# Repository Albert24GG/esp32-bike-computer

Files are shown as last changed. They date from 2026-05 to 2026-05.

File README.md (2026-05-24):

# Wireless Bike Computer

Block diagram

This project is a small wireless bike computer built around two ESP32 modules. It measures wheel movement on the fork, sends the data wirelessly to a handlebar unit, computes ride metrics, and shows them on a touchscreen display.

The project also includes a simple Android app. The phone sends its current coordinates to the bike computer over BLE, and the main module can render offline map tiles from the SD card.

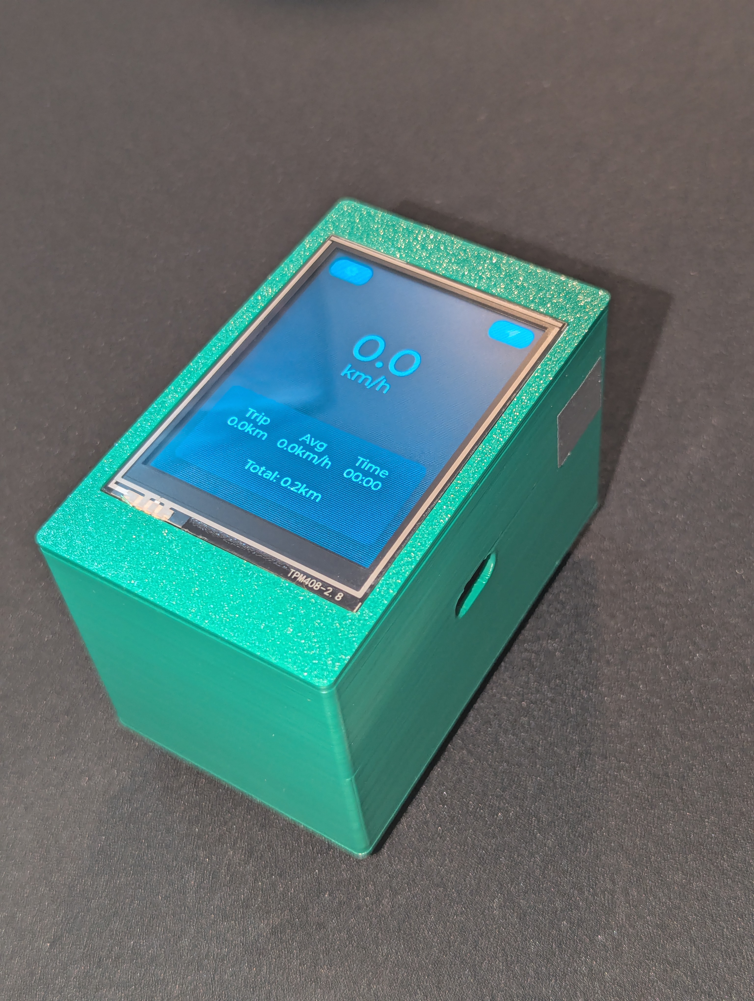
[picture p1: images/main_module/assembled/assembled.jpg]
Main module assembled


## What It Does

The system is split into three parts:

- The wheel module is mounted near the wheel. It uses a Hall effect sensor and a magnet to measure wheel revolutions.
- The main module is mounted on the handlebars. It receives wheel packets, computes the metrics, handles the UI, stores persistent data, and renders maps.
- The Android app runs on the phone. It scans for the bike computer over BLE and sends location coordinates to it.

The two ESP32 modules communicate using ESP-NOW. The main module communicates with the phone using Bluetooth Low Energy.

Main features:

- Current speed
- Trip distance
- Average speed
- Moving time
- Total distance
- Touchscreen UI with metrics, maps, and settings screens
- Persistent settings and ride metrics using NVS
- Configurable wheel circumference, units, brightness, and sleep timeout
- BLE location transfer from Android
- Offline slippy-map tile rendering from SD card
- 3D printed cases for both modules

## How It Works

The wheel module is based on a Seeed Studio XIAO ESP32-C6. It uses the low-power core to detect wheel events and measure the time between revolutions. The high-performance core stays in deep sleep most of the time and only wakes up when data needs to be sent.

The wheel module sends packets that contain:

- a sequence number
- cumulative wheel rotations
- cumulative moving time
- recent wheel periods

The main module is based on a Seeed Studio XIAO ESP32-S3. It receives these packets using ESP-NOW, validates them, computes the ride metrics, and updates the LVGL interface. Metrics are stored internally in metric units and converted only when they are shown on screen.

For the maps screen, the main module starts BLE advertising when the user presses the pairing button. The Android app connects to it and writes the current phone coordinates to a BLE characteristic. The firmware then projects the coordinates to slippy-map tile coordinates and renders the needed RGB565 tiles from the SD card. The current location marker stays fixed in the center of the map viewport.

## Photos

| Main module | Wheel module |
| --- | --- |
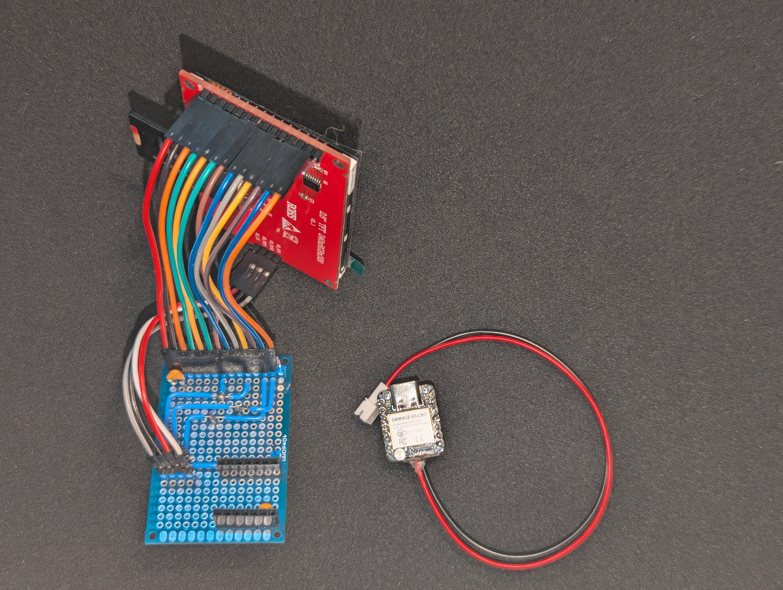
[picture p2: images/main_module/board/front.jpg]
Main module board
|  | Wheel module board |
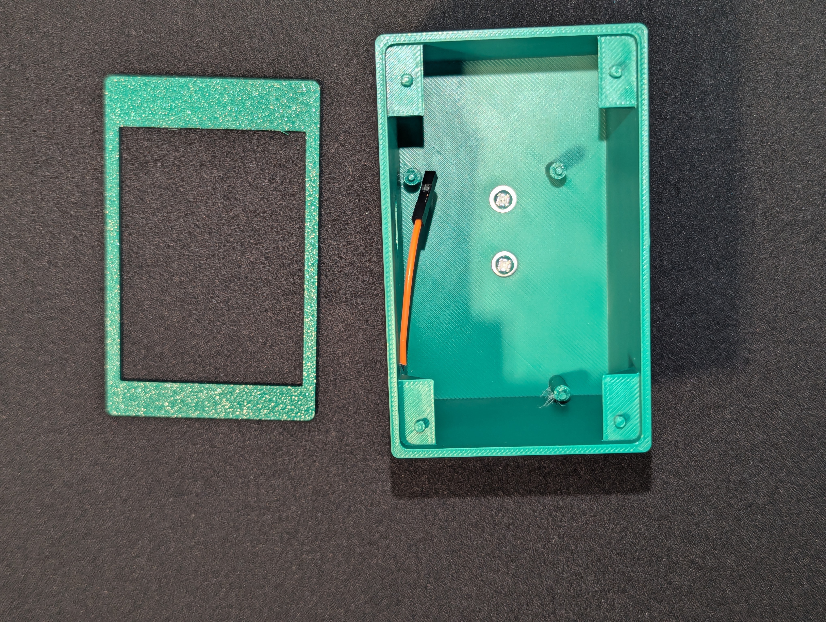
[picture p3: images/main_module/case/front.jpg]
Main module case
|  | Wheel module case |

UI screens:

| Metrics | Maps | Settings |
| --- | --- | --- |
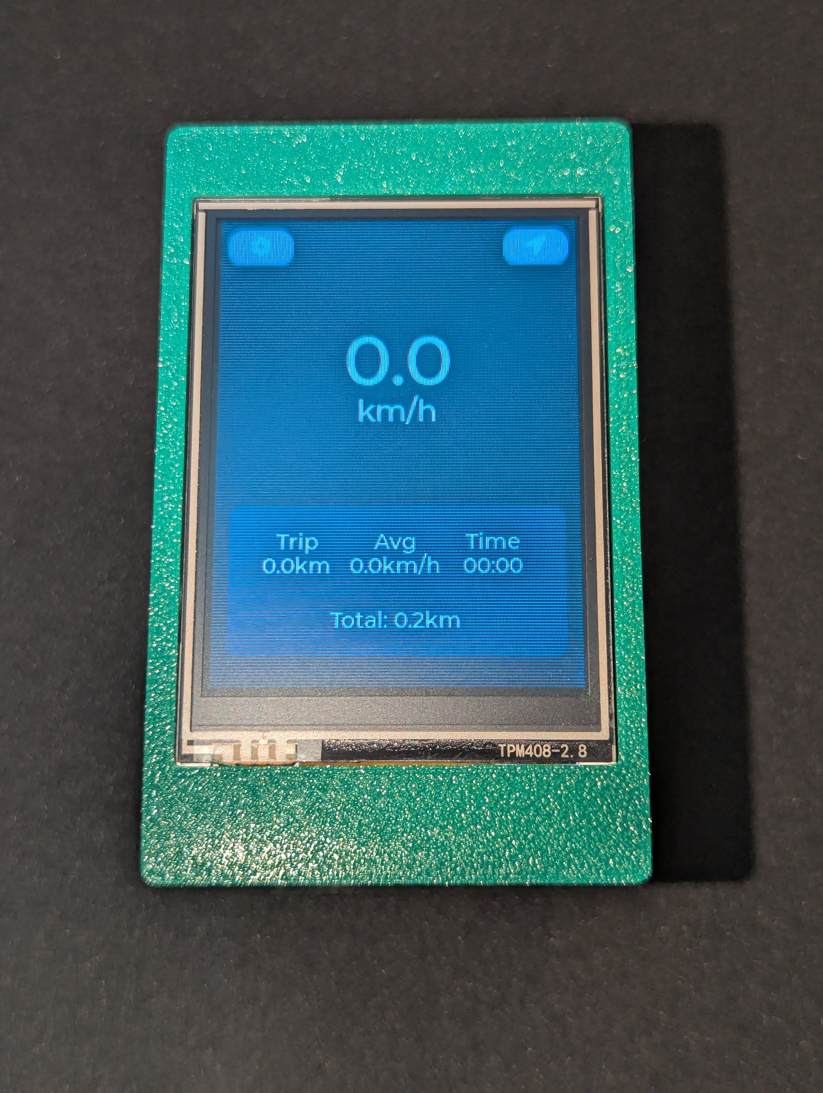
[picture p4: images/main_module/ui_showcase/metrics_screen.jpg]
Metrics screen
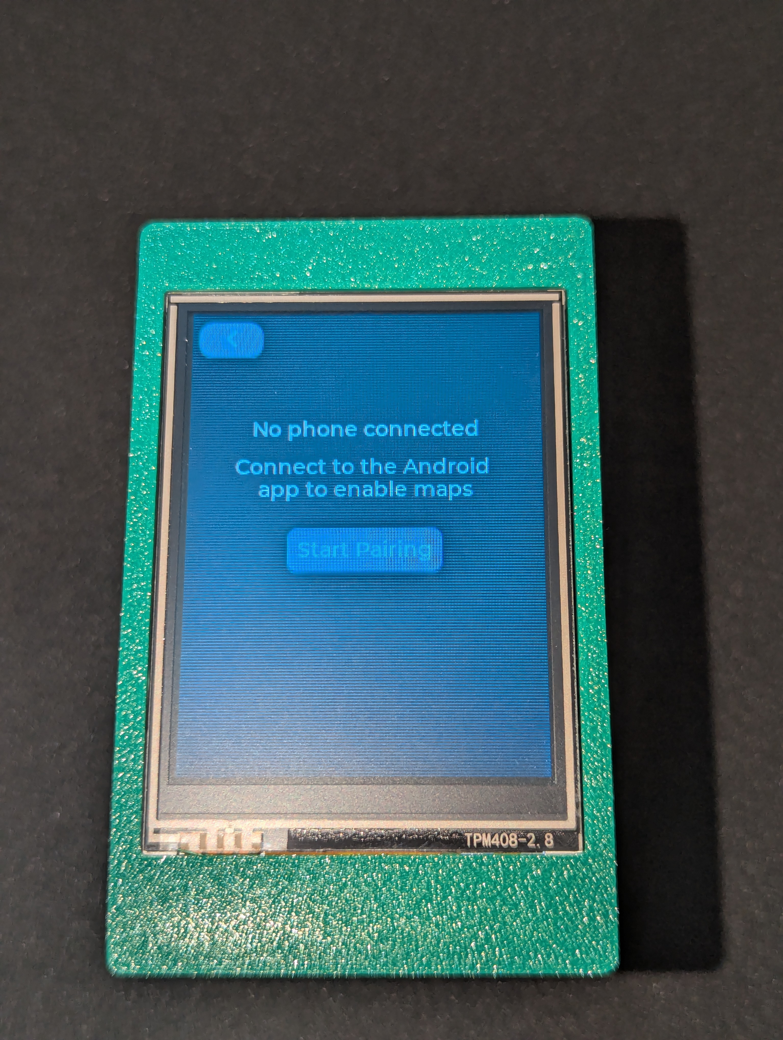
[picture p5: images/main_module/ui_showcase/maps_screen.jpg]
Maps screen
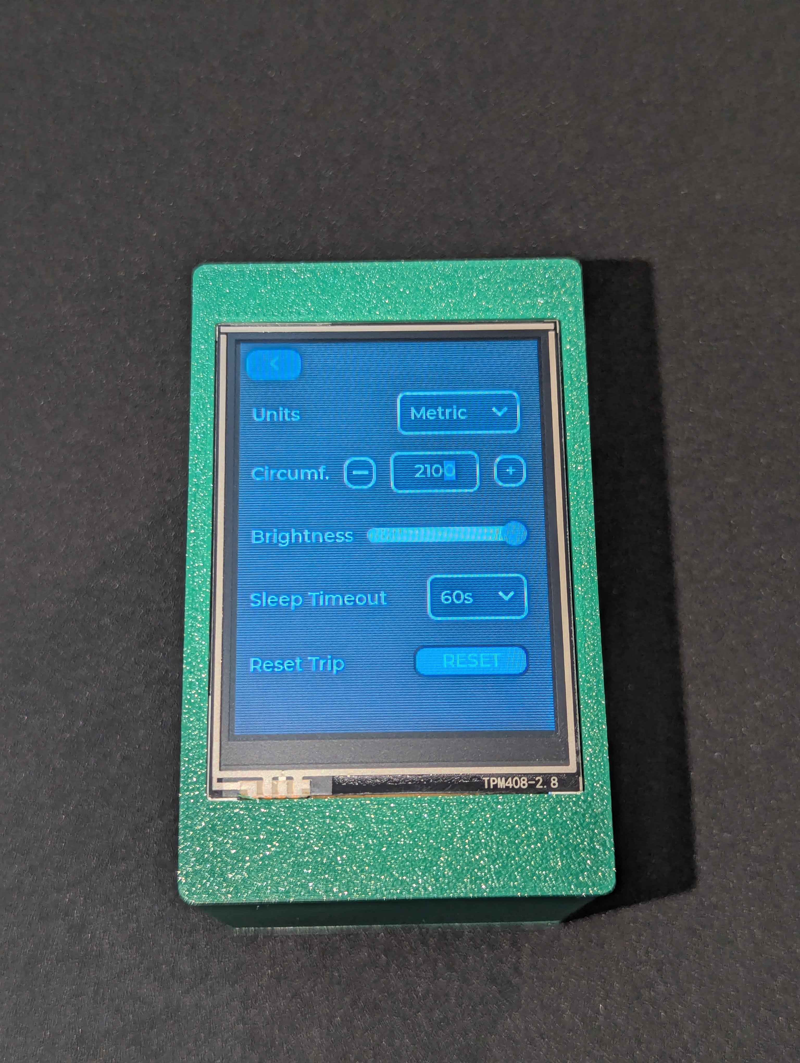
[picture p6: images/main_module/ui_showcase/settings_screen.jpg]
Settings screen
|  |  |  |

## Hardware

### Wheel Module

Main parts:

- Seeed Studio XIAO ESP32-C6
- US5881 Hall effect sensor
- Magnet attached to a wheel spoke
- 5 V boost converter for the Hall sensor
- LiPo battery
- Pull-up resistor and decoupling capacitors

Pinout:

| ESP32-C6 pin | Function |
| --- | --- |
| GPIO0 | Hall effect sensor output |

### Main Module

Main parts:

- Seeed Studio XIAO ESP32-S3
- 2.8 inch ILI9341 display
- XPT2046 touch controller
- SD card reader
- LiPo battery

Pinout:

| ESP32-S3 pin | Function |
| --- | --- |
| GPIO1 | Capacitive touch wake pin |
| GPIO2 | Touch CS |
| GPIO3 | LCD backlight PWM |
| GPIO4 | LCD D/C |
| GPIO5 | LCD reset |
| GPIO6 | LCD CS |
| GPIO7 | SPI CLK, shared |
| GPIO8 | SPI MISO, shared |
| GPIO9 | SPI MOSI, shared |
| GPIO43 | SD card CS |
| GPIO44 | Free |

The LCD, touch controller, and SD card reader share the same SPI bus. Each device has its own chip-select line.

The electrical schematic is available in [`hardware/electrical_schematic.pdf`](hardware/electrical_schematic.pdf). The KiCad project is in [`hardware/bike_computer/`](hardware/bike_computer/).

## Mechanical Design

The project includes 3D printed cases for both modules. The models are in [`mechanical/`](mechanical/).

Main files:

- Main module case: [`mechanical/models/main_module/`](mechanical/models/main_module/)
- Wheel module case: [`mechanical/models/wheel_module/`](mechanical/models/wheel_module/)
- Assembled Fusion models: [`mechanical/models/assembled/`](mechanical/models/assembled/)

The main module case includes a Garmin quarter-turn mount model, so it can be mounted on the handlebars in a similar way to common bike computers.

## Software Structure

The source code is inside [`src/`](src/).

```text
src/
  modules/
    common/        shared ESP-NOW packet definition
    wheel_module/  ESP32-C6 wheel sensor firmware
    main_module/   ESP32-S3 display and application firmware
  android-app/     Android companion app
  tools/           helper tools, including map tile conversion
```

The main module firmware is split into:

- `constants/` for pin assignments and configuration values
- `hardware/` for SPI, display, touch, and SD card setup
- `app/` for the application logic, metrics, storage, BLE, UI presenter, and map renderer
- `components/ui/` for the Squareline Studio generated LVGL UI

The Android app is written in Kotlin. It uses a foreground service for BLE scanning, BLE connection state, location updates, and retrying location writes while the phone screen is off.

## Maps

The firmware does not decode PNG or JPG tiles directly on the ESP32. The tiles are converted on the computer to raw RGB565 files and then copied to the SD card.

The expected SD card layout is:

```text
/sdcard/maps/<zoom>/<x>/<y>.rgb565
```

For example, for zoom level 16:

```text
/sdcard/maps/16/37474/23718.rgb565
```

The conversion tool is:

```sh
python3 src/tools/convert_raster_tiles.py <input-tile-root> <format> <output-root>
```

Example:

```sh
python3 src/tools/convert_raster_tiles.py raster_tiles_example/Bucharest/16 png raster_tiles_converted/16 --overwrite
```

The output directory can then be copied to the SD card under `maps/16`.

## Setup

Required tools:

- ESP-IDF 6.0.1 or a compatible ESP-IDF version
- Python 3
- Android Studio for the Android app
- Pillow and optionally NumPy for the tile conversion tool
- Squareline Studio only if the UI project needs to be edited

Install Python dependencies for the tile converter:

```sh
python3 -m pip install pillow numpy
```

The ESP-IDF projects use `sdkconfig.defaults`, so the target and important options should already be set. The main module enables PSRAM because the map canvas buffer is too large for internal SRAM.

## Build and Flash

### Wheel Module

```sh
cd src/modules/wheel_module
idf.py build
idf.py flash monitor
```

This builds and flashes the ESP32-C6 wheel module firmware.

### Main Module

```sh
cd src/modules/main_module
idf.py build
idf.py flash monitor
```

This builds and flashes the ESP32-S3 main module firmware.

### Android App

```sh
cd src/android-app
./gradlew assembleDebug
```

The generated debug APK can be installed from Android Studio or with `adb install`.

The app needs Bluetooth, location, and notification permissions. Location must also be enabled on the phone.

## Running the System

1. Flash the wheel module and main module.
2. (Optional) Copy converted map tiles to the SD card under `maps/<zoom>/`, then insert the SD card into the display module .
4. Power the wheel module and place the magnet near the Hall sensor path.
5. Power the main module.
6. (Optional) Open the Android app.
7. (Optional) Go to the maps screen on the bike computer and press the pairing button.
8. (Optional) Start scanning in the Android app.

After the phone connects, the app sends coordinates to the ESP32-S3 and the maps screen updates with the current location.

## Current Limitations

- The map zoom level is fixed in firmware.
- The project is still a prototype, with hand-wired hardware.
- Battery percentage measurement is not implemented yet.
- Map data must be prepared manually and copied to the SD card.
- BLE and ESP-NOW share the same 2.4 GHz radio, so connection behavior can depend on signal conditions and phone behavior.

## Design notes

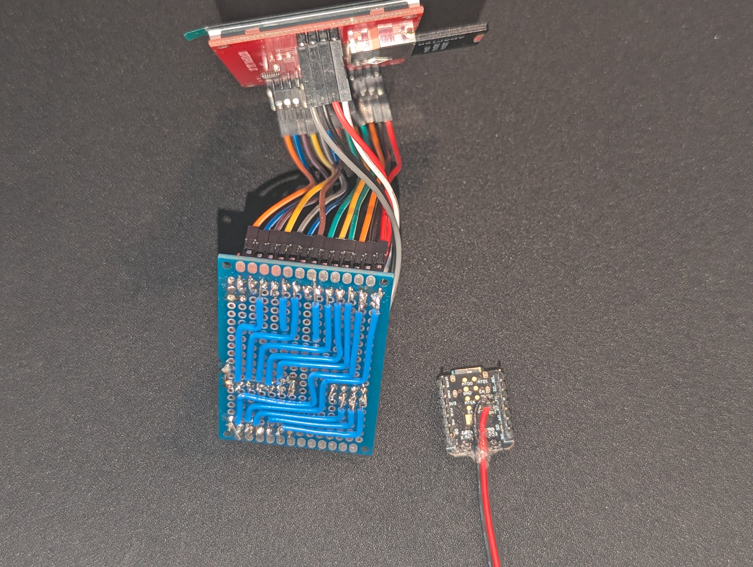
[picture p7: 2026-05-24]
images/main_module/board/back.jpg

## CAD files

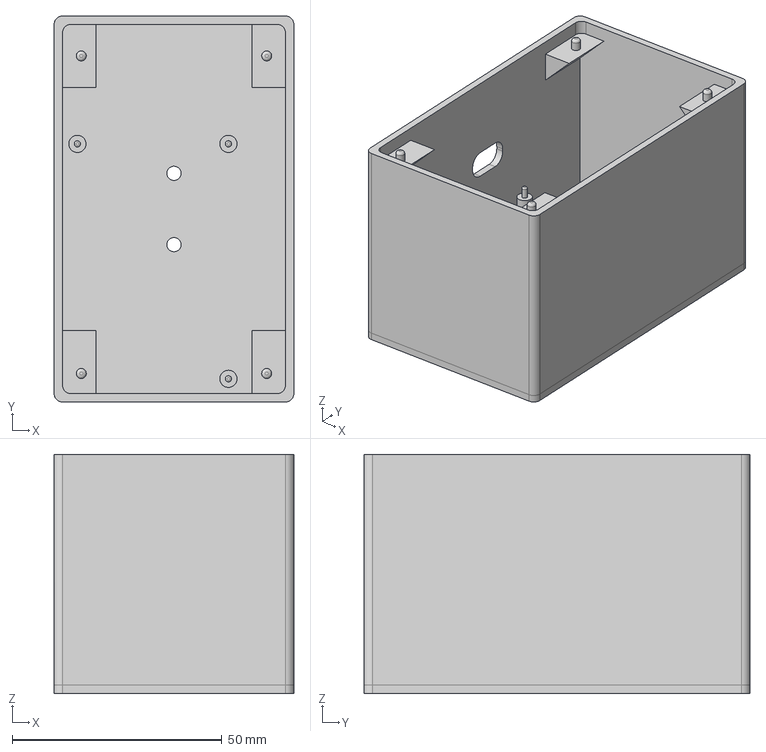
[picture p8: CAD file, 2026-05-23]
mechanical/models/main_module/bottom_case/BottomCase.step
57.1 x 92.0 x 57.0 mm

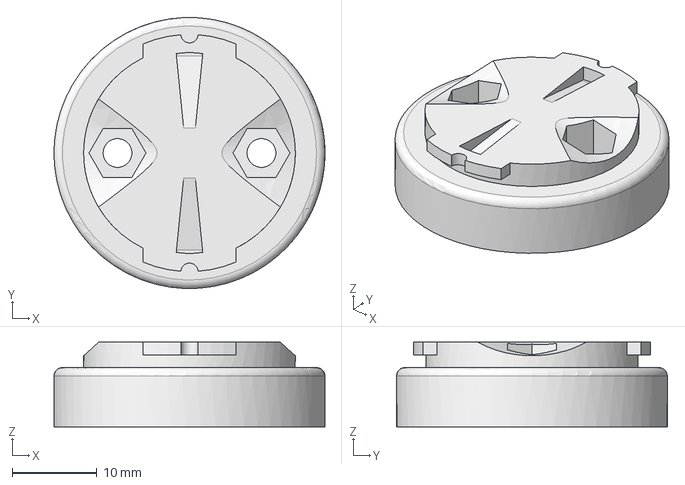
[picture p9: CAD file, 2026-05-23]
mechanical/models/main_module/garmin_mount/Quarter-turn_v6.step
32.0 x 32.0 x 10.0 mm

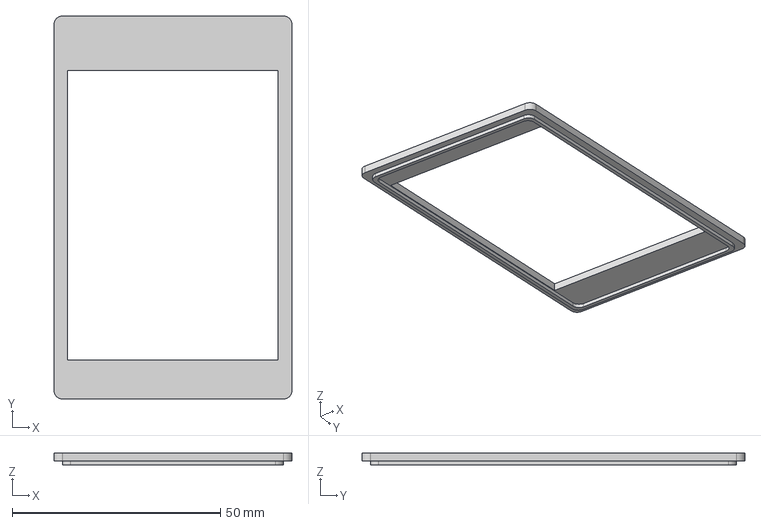
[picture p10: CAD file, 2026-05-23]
mechanical/models/main_module/top_lid/TopLid.step
57.1 x 92.0 x 3.00 mm

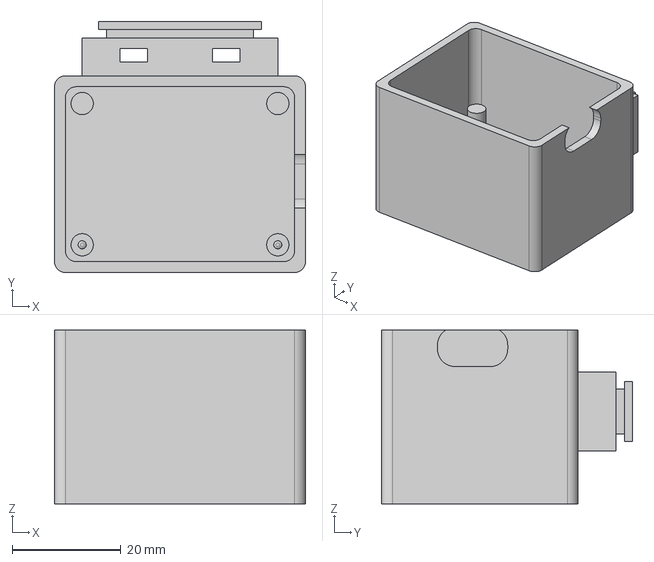
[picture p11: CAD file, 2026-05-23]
mechanical/models/wheel_module/bottom_case/BottomCase.step
46.2 x 46.2 x 32.0 mm

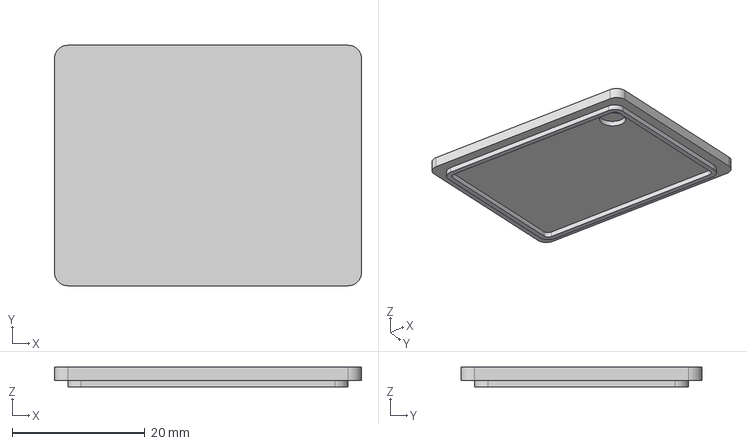
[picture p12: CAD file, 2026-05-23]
mechanical/models/wheel_module/top_lid/TopLid.step
46.2 x 36.2 x 3.00 mm

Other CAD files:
mechanical/models/main_module/bottom_case/BottomCase.3mf
mechanical/models/main_module/garmin_mount/Quarter-turn_v6.3mf
mechanical/models/main_module/top_lid/TopLid.3mf
mechanical/models/wheel_module/bottom_case/BottomCase.3mf
mechanical/models/wheel_module/top_lid/TopLid.3mf

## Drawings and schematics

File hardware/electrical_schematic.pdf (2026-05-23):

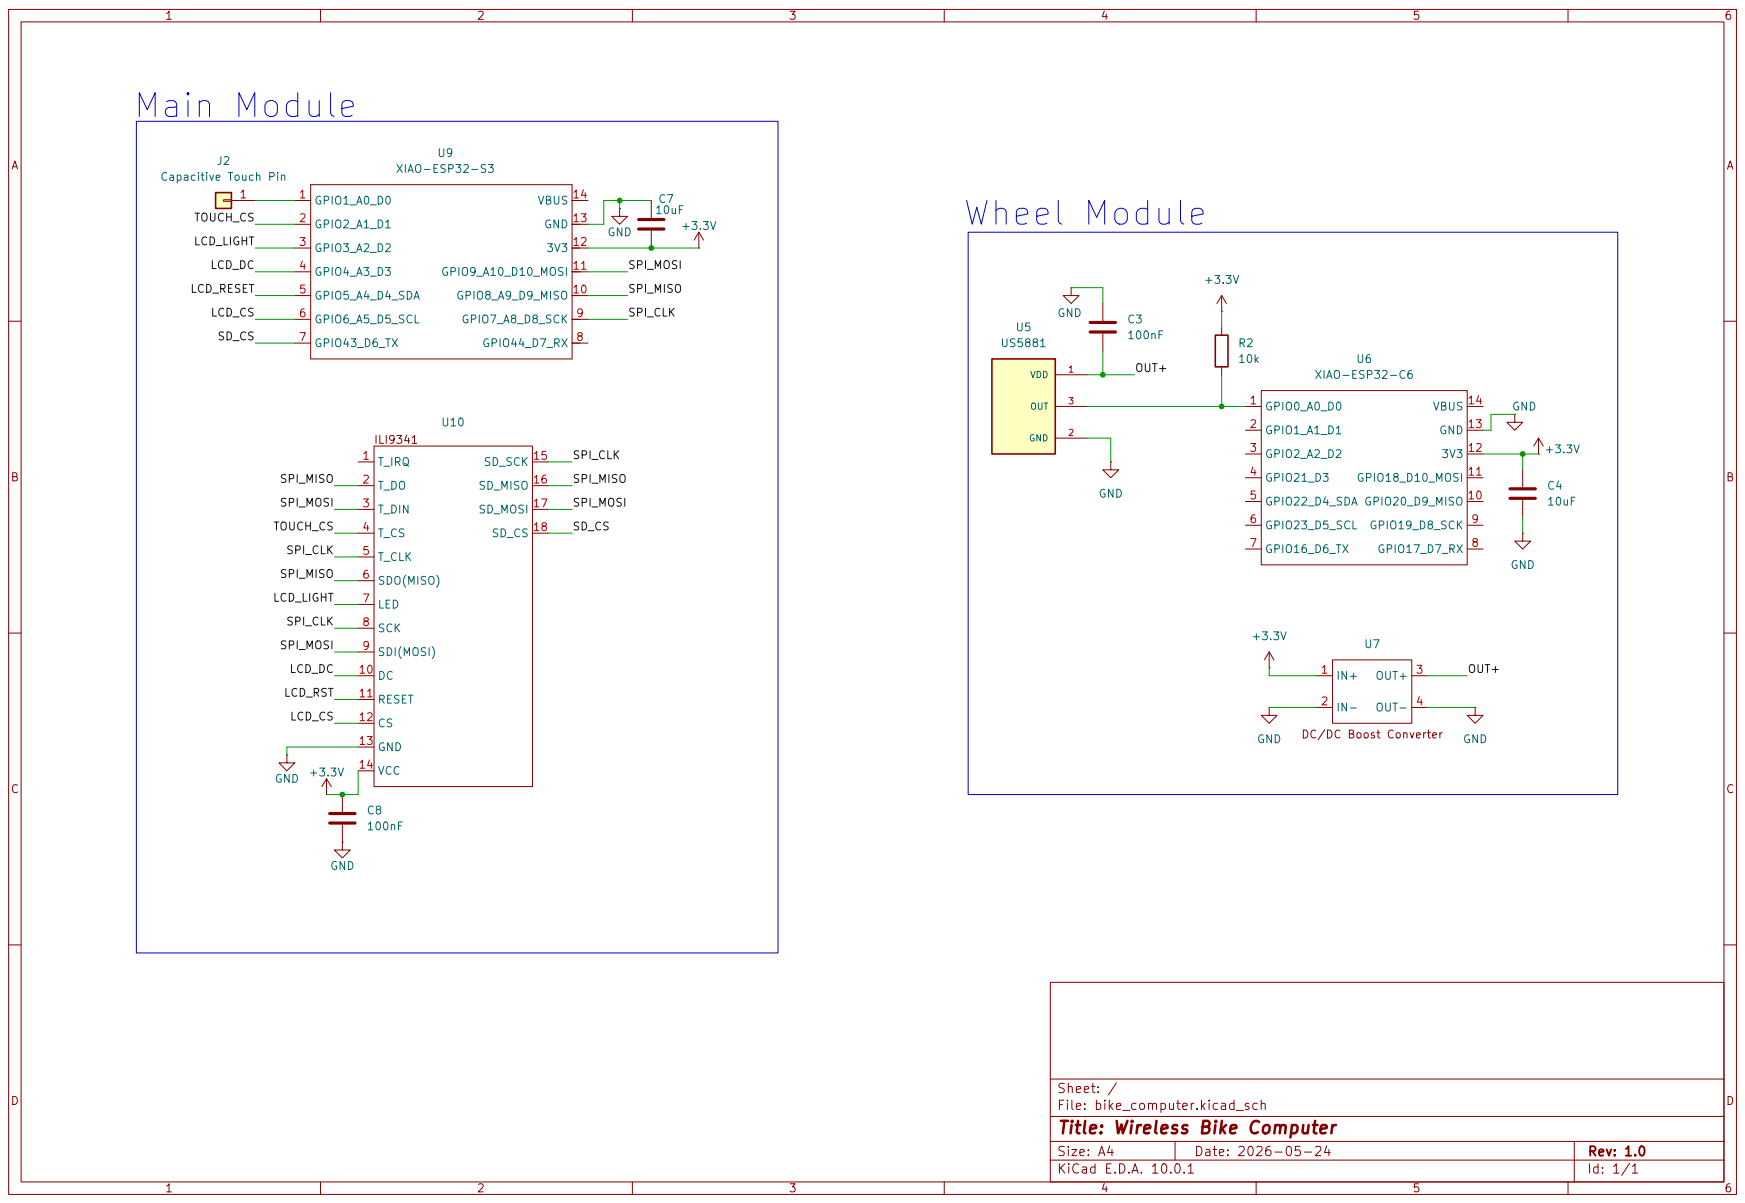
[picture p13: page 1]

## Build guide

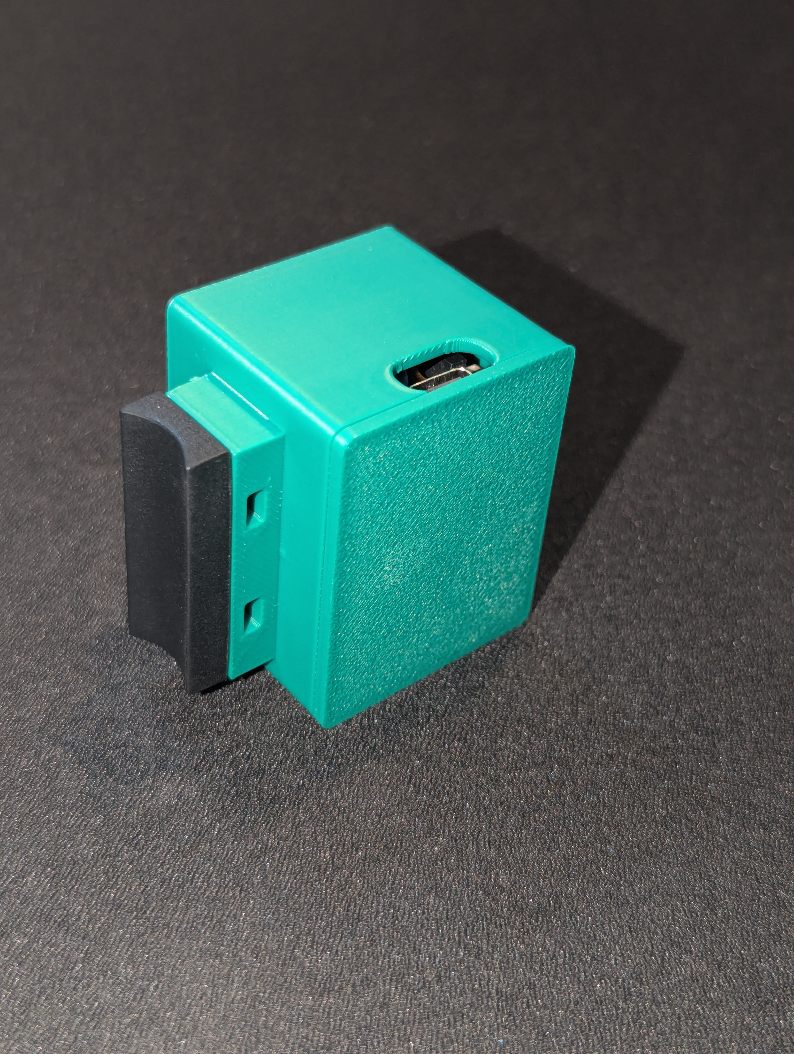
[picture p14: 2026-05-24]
images/wheel_module/assembled/assembled.jpg

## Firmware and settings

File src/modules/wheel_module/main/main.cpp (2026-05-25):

#include "driver/rtc_io.h"
#include "driver/uart.h"
#include "esp_attr.h"
#include "esp_err.h"
#include "esp_log.h"
#include "esp_now.h"
#include "esp_private/esp_clk.h"
#include "esp_sleep.h"
#include "esp_wifi.h"
#include "nvs.h"
#include "nvs_flash.h"
#include "soc/rtc.h"
#include "ulp_lp_core.h"

#include "../../common/espnow_packet.hpp"
#include "ulp_main.h"

#include "constants.hpp"
#include <cstdint>

extern const uint8_t ulp_main_bin_start[] asm("_binary_ulp_main_bin_start");
extern const uint8_t ulp_main_bin_end[] asm("_binary_ulp_main_bin_end");

static RTC_DATA_ATTR size_t wakeup_cnt_since_recalibration = 0;
static RTC_DATA_ATTR uint64_t packet_seq = 1;
static RTC_DATA_ATTR uint32_t wheel_boot_id = 0;
static RTC_DATA_ATTR uint32_t slowclk_cal_value = esp_clk_slowclk_cal_get();
static RTC_DATA_ATTR uint64_t cumulative_rotations = 0;
static RTC_DATA_ATTR uint64_t cumulative_ride_time_us = 0;

static uint64_t *shared_periods_buf =
    reinterpret_cast<uint64_t *>(ulp_shared_periods_buf);
static uint32_t &shared_periods_buf_len = ulp_shared_periods_buf_len;
static uint32_t &is_first_wakeup = ulp_is_first_wakeup;
static uint32_t &entered_inactive_state = ulp_entered_inactive_state;

static void init_wifi();
static void init_espnow();
static void init_nvs();
static void init_wheel_boot_id();
static void send_packet(const uint64_t *periods_us, size_t periods_len);
static void recalibrate_slow_clock();

static void wakeup_gpio_init() {
  /* Configure the Hall effect sensor GPIO as input, enable wakeup */
  rtc_gpio_init(SENSOR_PIN);
  rtc_gpio_set_direction(SENSOR_PIN, RTC_GPIO_MODE_INPUT_ONLY);
  rtc_gpio_pulldown_dis(SENSOR_PIN);
  rtc_gpio_pullup_en(SENSOR_PIN);
  rtc_gpio_wakeup_enable(SENSOR_PIN, GPIO_INTR_NEGEDGE);
}

static void
start_ulp_program(uint32_t wakeup_source,
                  uint32_t timer_sleep_duration_us = LP_TIMER_DURATION_US) {
  /* Start the program */
  ulp_lp_core_cfg_t cfg = {
      .wakeup_source = wakeup_source,
      .lp_timer_sleep_duration_us = timer_sleep_duration_us,
  };

  ESP_ERROR_CHECK(ulp_lp_core_run(&cfg));
}

static void
init_ulp_program(uint32_t wakeup_source,
                 uint32_t timer_sleep_duration_us = LP_TIMER_DURATION_US) {
  esp_err_t err = ulp_lp_core_load_binary(
      ulp_main_bin_start, (ulp_main_bin_end - ulp_main_bin_start));
  ESP_ERROR_CHECK(err);
  start_ulp_program(wakeup_source, timer_sleep_duration_us);
}

static void enter_inactive_state() {
  ESP_LOGI(TAG, "Entering inactive state due to inactivity timeout");

  entered_inactive_state = 1;
  is_first_wakeup = 1;
  start_ulp_program(ULP_LP_CORE_WAKEUP_SOURCE_LP_IO);
}

static void exit_inactive_state() {
  ESP_LOGI(TAG, "Exiting inactive state");

  entered_inactive_state = 0;
  start_ulp_program(ULP_LP_CORE_WAKEUP_SOURCE_LP_IO |
                    ULP_LP_CORE_WAKEUP_SOURCE_LP_TIMER);
}

static void handle_ulp_wakeup() {
  ++wakeup_cnt_since_recalibration;

  if (entered_inactive_state == 1 ||
      wakeup_cnt_since_recalibration >= WAKEUP_CNT_BEFORE_RECALIBRATION) {
    wakeup_cnt_since_recalibration = 0;
    recalibrate_slow_clock();
  }

  ulp_lp_core_stop();

  const uint32_t buf_len =
      std::min(shared_periods_buf_len, SHARED_PERIODS_BUF_SIZE);

  if (buf_len > 0) {
    uint64_t periods_buf[SHARED_PERIODS_BUF_SIZE] = {};

    memcpy(periods_buf, shared_periods_buf, buf_len * sizeof(periods_buf[0]));
    shared_periods_buf_len = 0;

    if (entered_inactive_state == 1) {
      entered_inactive_state = 0;
    }

    start_ulp_program(ULP_LP_CORE_WAKEUP_SOURCE_LP_IO |
                      ULP_LP_CORE_WAKEUP_SOURCE_LP_TIMER);

    uint32_t valid_periods_cnt = 0;
    for (size_t i = 0; i < buf_len; ++i) {
      const uint64_t period_us =
          rtc_time_slowclk_to_us(periods_buf[i], slowclk_cal_value);
      if (period_us < MIN_VALID_PERIOD_US) {
        continue;
      }

      periods_buf[valid_periods_cnt++] = period_us;
    }

    send_packet(periods_buf, valid_periods_cnt);

  } else {
    if (entered_inactive_state == 1) {
      exit_inactive_state();
    } else {
      enter_inactive_state();
    }
  }
}

extern "C" void app_main(void) {
  ESP_LOGI(TAG, "Starting HP core\n");

  wakeup_gpio_init();

  if (esp_sleep_get_wakeup_causes() & BIT(ESP_SLEEP_WAKEUP_ULP)) {
    ESP_LOGI(TAG, "Woke up from ULP wakeup");

    handle_ulp_wakeup();
  } else {
    ESP_LOGI(TAG, "Not a ULP wakeup, initializing it!");
    init_wheel_boot_id();
    init_ulp_program(ULP_LP_CORE_WAKEUP_SOURCE_LP_IO |
                     ULP_LP_CORE_WAKEUP_SOURCE_LP_TIMER);
  }

  ESP_ERROR_CHECK(esp_sleep_enable_ulp_wakeup());

  ESP_LOGI(TAG, "Entering deep sleep");

  uart_wait_tx_idle_polling((uart_port_t)CONFIG_ESP_CONSOLE_UART_NUM);
  esp_deep_sleep_start();
}

void init_nvs() {
  esp_err_t ret = nvs_flash_init();
  if (ret == ESP_ERR_NVS_NO_FREE_PAGES ||
      ret == ESP_ERR_NVS_NEW_VERSION_FOUND) {
    ESP_ERROR_CHECK(nvs_flash_erase());
    ESP_ERROR_CHECK(nvs_flash_init());
  } else {
    ESP_ERROR_CHECK(ret);
  }
}

void init_wheel_boot_id() {
  init_nvs();

  nvs_handle_t handle{};
  ESP_ERROR_CHECK(nvs_open("wheel", NVS_READWRITE, &handle));

  uint32_t stored_boot_id{};
  const esp_err_t read_err = nvs_get_u32(handle, "boot_id", &stored_boot_id);
  if (read_err != ESP_OK && read_err != ESP_ERR_NVS_NOT_FOUND) {
    nvs_close(handle);
    ESP_ERROR_CHECK(read_err);
  }

  ++stored_boot_id;
  if (stored_boot_id == 0) {
    stored_boot_id = 1;
  }

  ESP_ERROR_CHECK(nvs_set_u32(handle, "boot_id", stored_boot_id));
  ESP_ERROR_CHECK(nvs_commit(handle));
  nvs_close(handle);

  wheel_boot_id = stored_boot_id;
  packet_seq = 1;
  cumulative_rotations = 0;
  cumulative_ride_time_us = 0;

  ESP_LOGI(TAG, "Wheel boot session initialized: boot_id=%lu",
           static_cast<unsigned long>(wheel_boot_id));
}

void init_wifi() {
  init_nvs();

  ESP_ERROR_CHECK(esp_netif_init());
  ESP_ERROR_CHECK(esp_event_loop_create_default());

  wifi_init_config_t wifi_cfg = WIFI_INIT_CONFIG_DEFAULT();

  ESP_ERROR_CHECK(esp_wifi_init(&wifi_cfg));
  ESP_ERROR_CHECK(esp_wifi_set_storage(WIFI_STORAGE_RAM));
  ESP_ERROR_CHECK(esp_wifi_set_mode(WIFI_MODE_STA));
  ESP_ERROR_CHECK(esp_wifi_start());

  ESP_ERROR_CHECK(esp_wifi_set_channel(ESPNOW_CHANNEL, WIFI_SECOND_CHAN_NONE));
}

void init_espnow() {
  ESP_ERROR_CHECK(esp_now_init());
  ESP_ERROR_CHECK(esp_now_add_peer(&PEER_INFO));
}

static void send_packet(const uint64_t *periods_us, size_t periods_len) {
  init_wifi();
  init_espnow();

  BikePacket packet = {};
  packet.boot_id = wheel_boot_id;
  packet.seq_num = packet_seq++;
  packet.periods_buf_len =
      static_cast<uint8_t>(std::min(periods_len, max_periods_per_packet));

  memcpy(packet.periods_buf_us, periods_us,
         packet.periods_buf_len * sizeof(packet.periods_buf_us[0]));

  for (size_t i = 0; i < packet.periods_buf_len; ++i) {
    cumulative_ride_time_us += packet.periods_buf_us[i];
  }
  cumulative_rotations += packet.periods_buf_len;
  packet.cumulative_rotations = cumulative_rotations;
  packet.cumulative_ride_time_us = cumulative_ride_time_us;

  ESP_ERROR_CHECK(esp_now_send(DEST_MAC_ADDR.data(),
                               reinterpret_cast<const uint8_t *>(&packet),
                               sizeof(packet)));

  ESP_LOGI(TAG,
           "Sent packet with boot_id=%lu, seq_num=%llu, %u wheel periods, "
           "cumulative rotations=%llu, cumulative ride time=%llu us",
           static_cast<unsigned long>(packet.boot_id), packet.seq_num,
           packet.periods_buf_len, packet.cumulative_rotations,
           packet.cumulative_ride_time_us);
}

static void recalibrate_slow_clock() {
  const uint32_t new_slowclk_cal_value =
      rtc_clk_cal(CLK_CAL_RTC_SLOW, SLOW_CLK_CAL_CYCLES);
  if (new_slowclk_cal_value != slowclk_cal_value &&
      new_slowclk_cal_value != 0) {
    slowclk_cal_value = new_slowclk_cal_value;
    esp_clk_slowclk_cal_set(slowclk_cal_value);
  }
}

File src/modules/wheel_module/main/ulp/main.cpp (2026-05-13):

#include "hal/gpio_types.h"
#include "soc/lp_timer_struct.h"
#include "ulp_lp_core.h"
#include "ulp_lp_core_gpio.h"
#include "ulp_lp_core_interrupts.h"
#include "ulp_lp_core_utils.h"
#include <cstdint>
#include <cstring>
#include <limits>
#include <stdbool.h>

#include "constants.hpp"


volatile uint64_t shared_periods_buf[SHARED_PERIODS_BUF_SIZE] = {0};
volatile uint32_t shared_periods_buf_len = 0;
volatile uint32_t is_first_wakeup = 1;
volatile uint32_t entered_inactive_state = 0;

static uint64_t last_wheel_counter = 0;

struct CircularBuffer {
  static constexpr uint32_t capacity = LP_CIRCULAR_BUF_SIZE;
  uint64_t buffer[LP_CIRCULAR_BUF_SIZE] = {};
  uint32_t head = 0;
  uint32_t tail = 0;
  uint32_t len = 0;

  void push(uint64_t value) {
    if (len >= capacity) {
      return;
    }

    buffer[tail] = value;
    tail = (tail + 1) % capacity;
    ++len;
  }

  /*
   * @brief Pops the first n elements from the buffer and writes them to out_buf
   * @param n The number of elements to pop
   * @param out_buf The buffer to write the popped elements to. Must be at least
   * of size n.
   * @return The number of elements actually popped (which may be less than n if
   * the buffer doesn't contain enough elements)
   */
  uint32_t pop_first_n(uint32_t n, uint64_t *out_buf) {
    if (n == 0 || len == 0) {
      return 0;
    }

    const uint32_t to_pop = std::min(n, len);
    const uint32_t space_to_end = capacity - head;
    if (to_pop <= space_to_end) {
      // No wrap around
      memcpy(out_buf, buffer + head, to_pop * sizeof(uint64_t));
    } else {
      // Wrap around
      memcpy(out_buf, buffer + head, space_to_end * sizeof(uint64_t));
      memcpy(out_buf + space_to_end, buffer,
             (to_pop - space_to_end) * sizeof(uint64_t));
    }

    head = (head + to_pop) % capacity;
    len -= to_pop;

    return to_pop;
  }
};

static CircularBuffer circular_periods_buf{};

static uint32_t inactivity_cnt = 0;
static bool notify_hp = false;

static uint64_t read_counter(size_t idx) {
  LP_TIMER.update.update = 1;

  while (LP_TIMER.update.update) {
    // Wait for the update to complete
  }

  uint64_t lo = LP_TIMER.counter[idx].lo.counter_lo;
  uint64_t hi = LP_TIMER.counter[idx].hi.counter_hi;
  uint64_t counter = (hi << 32) | lo;
  return counter;
}

static void update_wheel_periods_buf() {
  const uint64_t cur_counter = read_counter(0);

  const uint64_t cur_wheel_period = [&]() {
    if (cur_counter < last_wheel_counter) {
      // Handle counter overflow
      return (std::numeric_limits<uint64_t>::max() - last_wheel_counter) +
             cur_counter + 1;
    } else {
      return cur_counter - last_wheel_counter;
    }
  }();

  last_wheel_counter = cur_counter;

  if (is_first_wakeup == 1) {
    is_first_wakeup = 0;
  } else if (cur_wheel_period) {
    circular_periods_buf.push(cur_wheel_period);
  }
}

static void timer_handler() {
  ulp_lp_core_lp_timer_intr_clear();

  if (circular_periods_buf.len > 0) {
    if (shared_periods_buf_len == 0) {
      const uint32_t buf_len = circular_periods_buf.pop_first_n(
          SHARED_PERIODS_BUF_SIZE, const_cast<uint64_t *>(shared_periods_buf));

      shared_periods_buf_len = buf_len;
    }

    notify_hp = true;
    inactivity_cnt = 0;
    return;
  }

  ++inactivity_cnt;
  if (inactivity_cnt >= LP_WAKEUPS_BEFORE_TIMEOUT) {
    inactivity_cnt = 0;
    notify_hp = true;
  }
}

static void gpio_handler() {
  ulp_lp_core_gpio_clear_intr_status();

  update_wheel_periods_buf();

  if (circular_periods_buf.len >= SHARED_PERIODS_BUF_SIZE) {
    if (shared_periods_buf_len == 0) {
      const uint32_t popped = circular_periods_buf.pop_first_n(
          SHARED_PERIODS_BUF_SIZE, const_cast<uint64_t *>(shared_periods_buf));

      shared_periods_buf_len = popped;
    }

    notify_hp = true;
  }

  if (entered_inactive_state == 1) {
    notify_hp = true;
  }

  inactivity_cnt = 0;
}

int main(void) {

  const auto wakeup_cause = ulp_lp_core_get_wakeup_cause();

  if (wakeup_cause & ULP_LP_CORE_WAKEUP_SOURCE_LP_IO) {
    gpio_handler();
  } else if (wakeup_cause & ULP_LP_CORE_WAKEUP_SOURCE_LP_TIMER) {
    timer_handler();
  }

  if (notify_hp) {
    notify_hp = false;
    ulp_lp_core_wakeup_main_processor();
  }

  return 0;
}

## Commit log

2026-05-08 Add schematic
    [bike_computer.kicad_sch]
2026-05-10 Implement main sensor logic
2026-05-10 Fix ULP program initialization & use esp-idf logging
    [main.cpp]
2026-05-12 Update the partition table for the main module
    [partitions.csv]
2026-05-13 Bug fixing: esp-now & app initialization
    [app.cpp, main.cpp]
2026-05-13 Fix several issues in wheel module code
    [main.cpp]
2026-05-15 Remove redundant log prints
2026-05-15 Fix log printing format string
    [app.cpp]
2026-05-17 Update board pinout
2026-05-23 Use the event loop for the persistence save timer
2026-05-23 Tighten BLE pairing latency
2026-05-23 Fix color accuracy by using BGR order
    [ili9341_display.cpp]
2026-05-23 Add 3d models
    [BottomCase.3mf, BottomCase.step, Quarter-turn_v6.3mf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]
2026-05-23 Update schematic with new pinout
    [bike_computer.kicad_sch]
2026-05-24 Skip maps rendering when maps screen is inactive
    [app.cpp]
2026-05-24 Use Material You API
2026-05-25 Remove debugging led blink
2026-05-25 Handle wheel module power losses using a `boot_id`
